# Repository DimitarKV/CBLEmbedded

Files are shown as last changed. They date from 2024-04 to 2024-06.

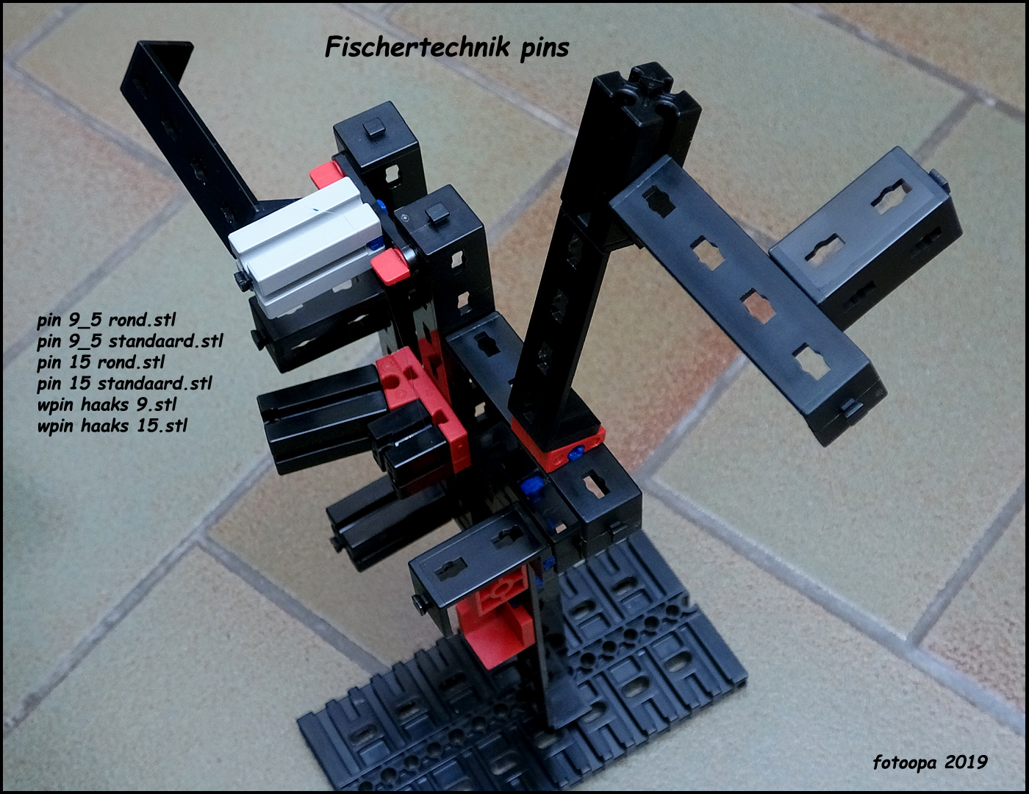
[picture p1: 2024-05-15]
Printing/Resources/Fischertechnik matching pins. - 4074749/images/DSC05036_pins.jpg

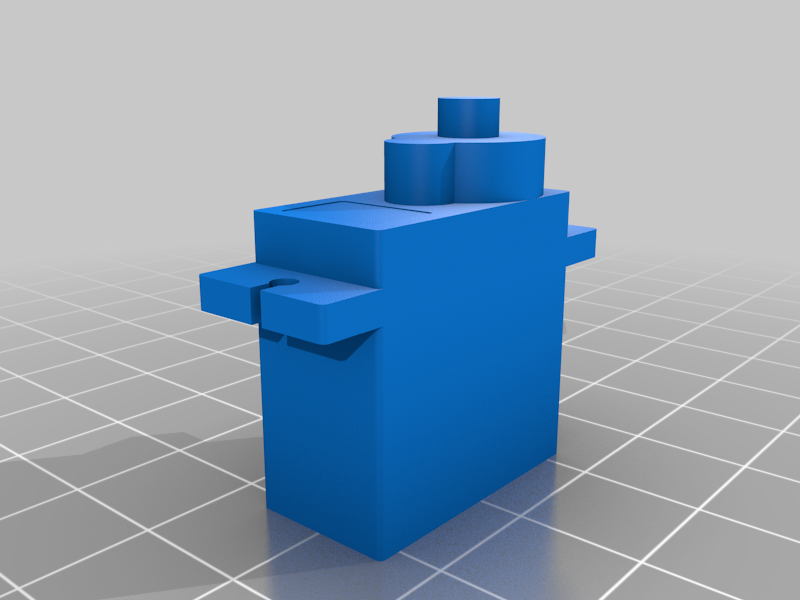
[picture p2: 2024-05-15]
Printing/Resources/Sg90 servo - 4315907/images/servoSg90.png

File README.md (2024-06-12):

# CBLEmbedded

## Description

A robot that simulates an unloading baggage-handling system in airports. In particular, it is intended to load a vehicle with luggage from an aircraft. Our baggage cart has three compartments, which will be filled by keeping their weights as equal as possible. The robot works on the principle that a new luggage is put in the most light-weighted compartment. There are two types of baggage – 10kg and 20kg. Luggage that was not intended for this flight will be placed in a separate container and moved to the lost and found. The capacity of each compartment is 40kg. When the current baggage cannot be stored in any of the compartments without exceeding the weight limit, the vehicle is ready to go. 

## How to use the project

- In the *Orchestrator* folder there are:
  - the Modbus Connector which creates another layer of abstraction over the Serial protocol used by both ends - ESP-32 and RaspberryPI;
  - the Driver which implements the whole logic of the robot using commands in the service layer;
  - the Portal which collects and preserves the measurements in csv files for later usage in our data model.
  - the Robot SeviceLayer which creates application specific implementation over Modbus;
  - the Simulation transfer server
- In the *Peripherals* folder there is implementation of functionality of the hardware devices, used in the robot:
  -  the Color sensor determines the behavior of the color sensor. Receives data and converts it in the needed form for the project;
  -  the Modbus connector handles Modbus communication over the serial connection. It includes methods for reading, decoding, processing, and responding to Modbus commands;
  -  the Depth sensor determines the behavior of the depth sensor. Receives data and converts it in the needed form for the project;
  -  the Motor driver controls a motor using four input pins. It provides methods to initialize the motor, move it by steps or length, check its status, and handle continuous movement;
  -  the Display determines the behavior of the display. Writes different type of messages depending on the state of the robot.
  -  the Servo controller manages multiple servos using the PCA9685 PWM driver. It provides methods to initialize the controller, add and configure servos, set angles immediately, and control servo progression;
  -  the Error prone device defines the basic functionality of the devices. Makes sure that the peripheral devices work properly;
  -  the Main manages various devices connected to the ESP-32.
- In the *Printing* folder there are 3D files of different holders for the hardware devices
- In the *Simulation* folder there is an exe file which contains the built simulation of the robot and all work files for the simulation created in Unity.

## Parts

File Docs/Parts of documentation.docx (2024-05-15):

// Commands:

// WDN{text} - Write Display No-scrolling, text is the string that is going to be displayed without scrolling.

// WDS{text} - Write Display Scrolling, text is the string that is going to be displayed scrolling on the screen.

// SSP{v1,v2,v3...} - Set Servo Values, set the corresponding values v1, v2, v3... to the corresponding servos.

// Handle collected serial commands from the buffer.

// We define a command name from the first three

// letters in the command, any consequent letters represent parameters.

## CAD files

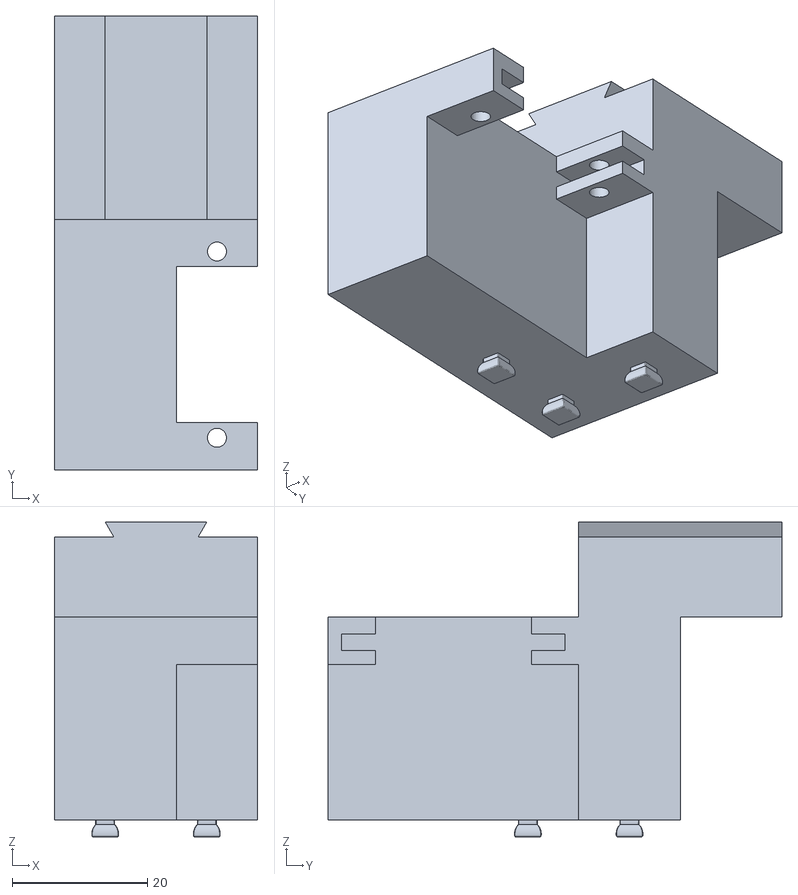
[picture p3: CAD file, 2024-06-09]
Printing/Ready/ServoPusherV7/Main frame.stl
30.0 x 67.0 x 46.5

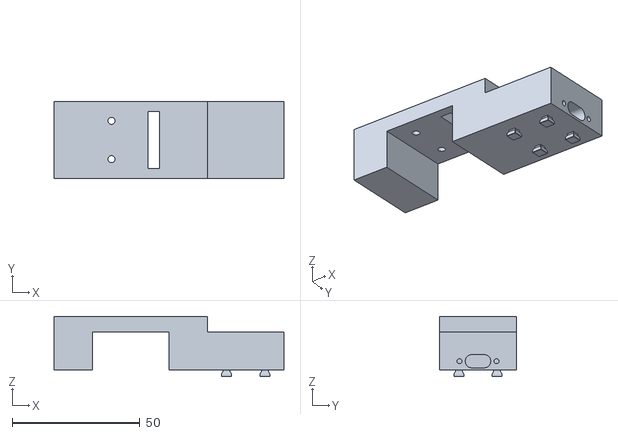
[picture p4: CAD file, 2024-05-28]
Printing/Ready/ColorDepthSensorMount/Frame.stl
90.0 x 30.0 x 23.5

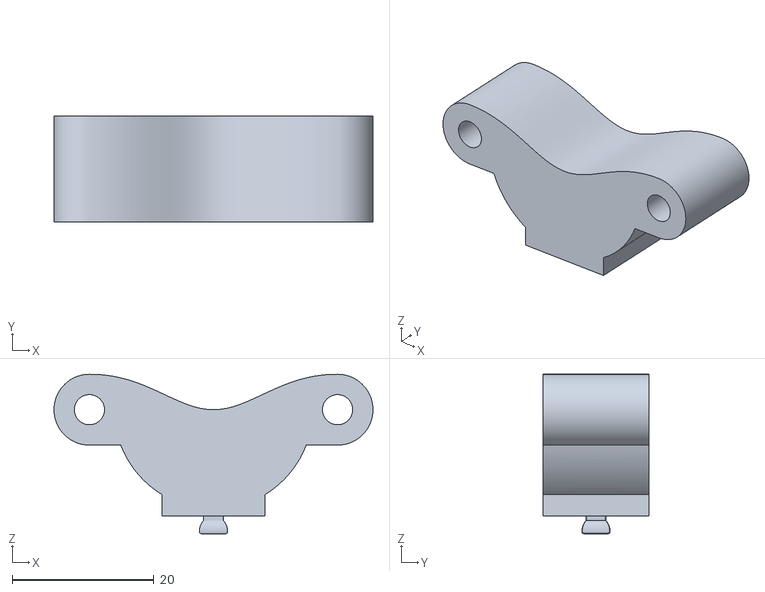
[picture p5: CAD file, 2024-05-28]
Printing/Ready/Motor/Mount.stl
45.0 x 15.0 x 22.5

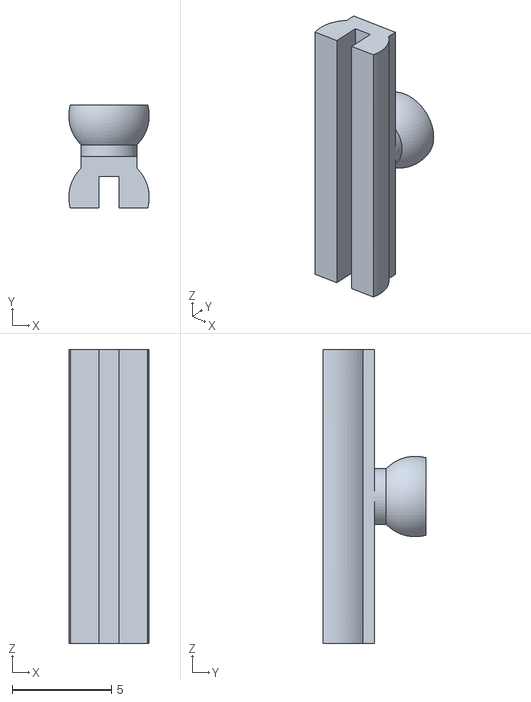
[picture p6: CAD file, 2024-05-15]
Printing/Resources/Fischertechnik matching pins. - 4074749/files/pin_15_rond.stl
4.05 x 5.20 x 14.8

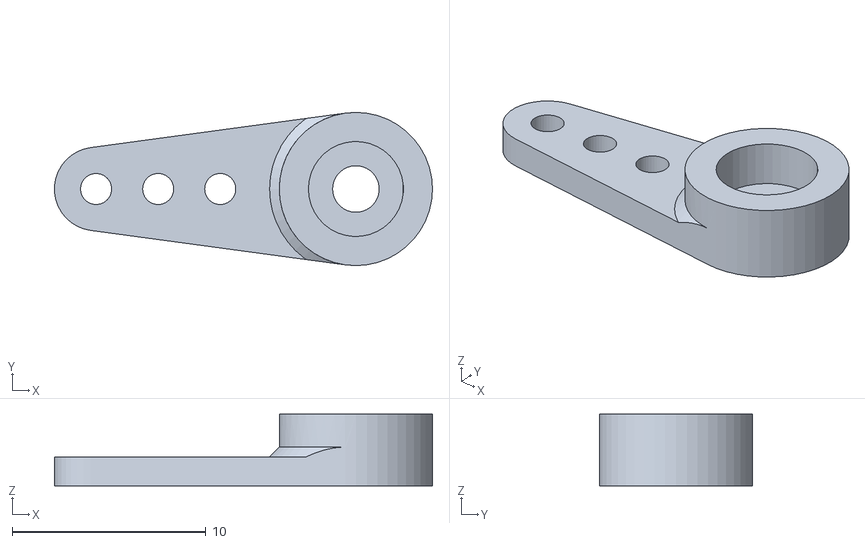
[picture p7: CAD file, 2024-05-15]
Printing/Resources/servo_arm.STL
19.5 x 7.90 x 3.70

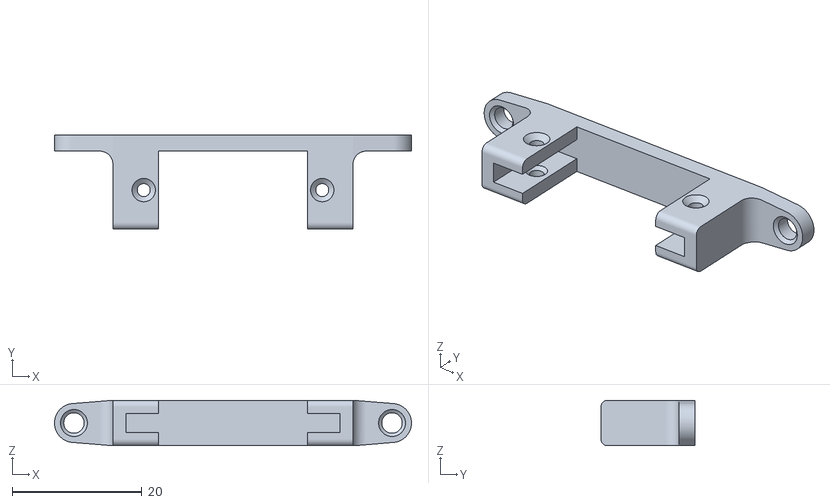
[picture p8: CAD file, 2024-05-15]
Printing/Resources/ServoMounts_SMA001_002_TERRN/PN_SMA002-4-24_TERRN.stl
55.0 x 14.5 x 7.00

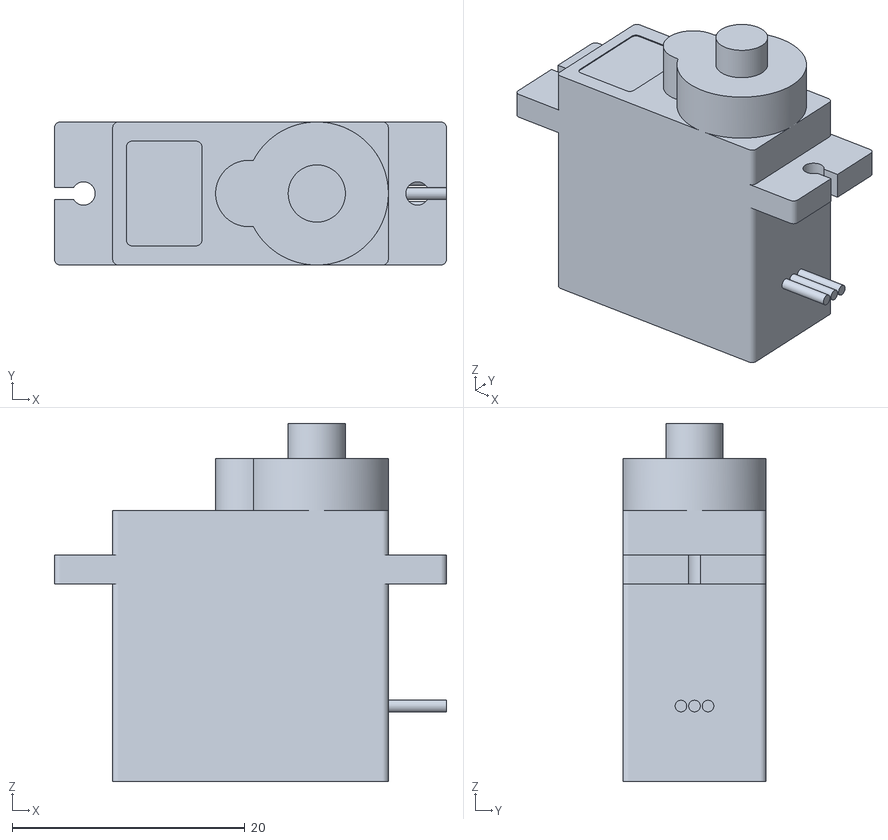
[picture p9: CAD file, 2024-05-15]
Printing/Resources/Sg90 servo - 4315907/files/servoSg90.stl
33.7 x 12.3 x 30.8

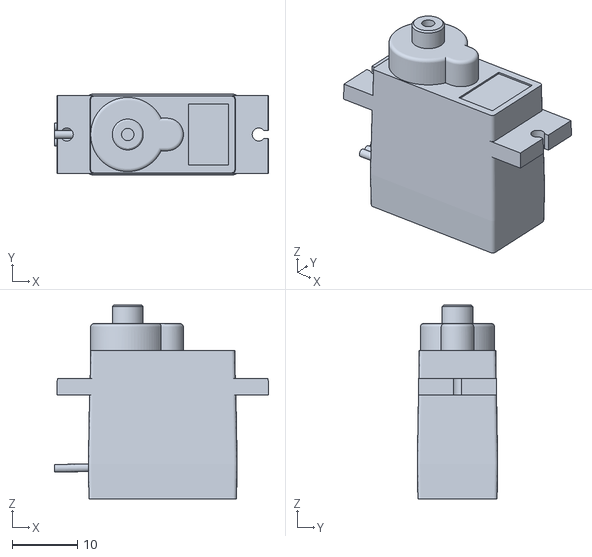
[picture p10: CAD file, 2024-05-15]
Printing/Resources/Tower Pro Micro Servo 9g SG90 - 787942/files/2051_servo_tower-pro-sg90.pk2.stl
32.9 x 12.4 x 29.8

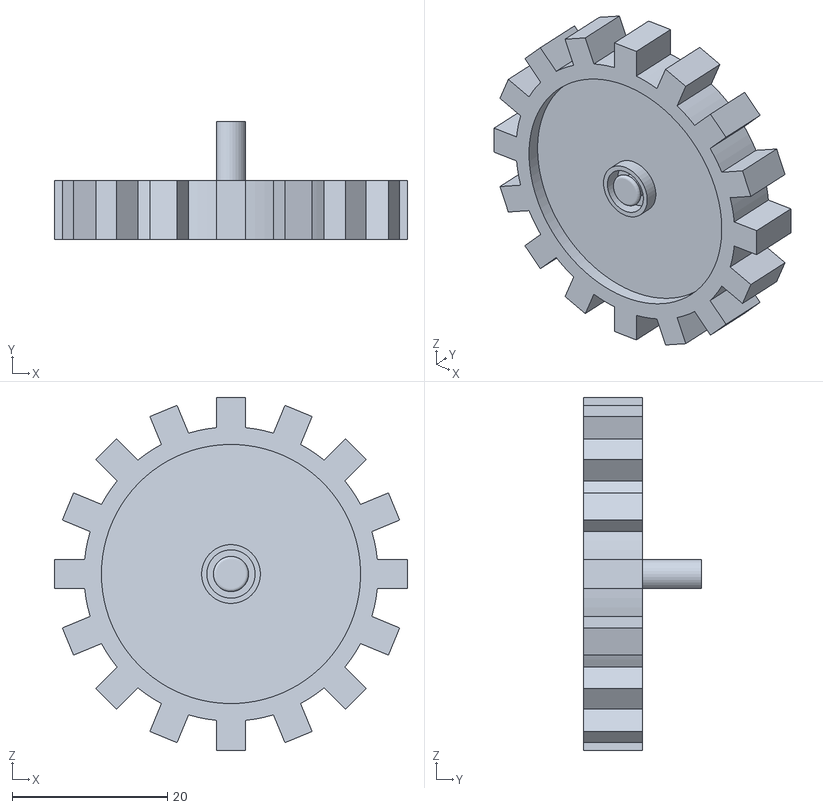
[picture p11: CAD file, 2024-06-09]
Simulation/LuggageSimulator/Assets/3DModels/gear wheel/gear wheel.stl
45.4 x 15.1 x 45.4

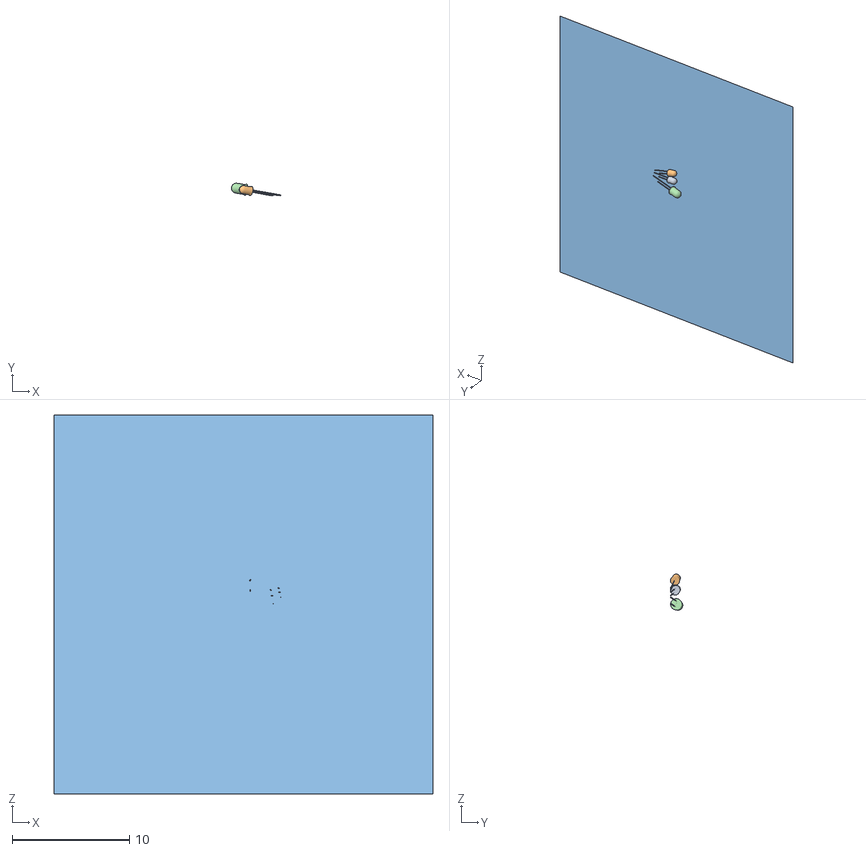
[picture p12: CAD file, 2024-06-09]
Simulation/LuggageSimulator/Assets/3DModels/Leds File/led.obj
32.3 x 1.08 x 32.3
Plane

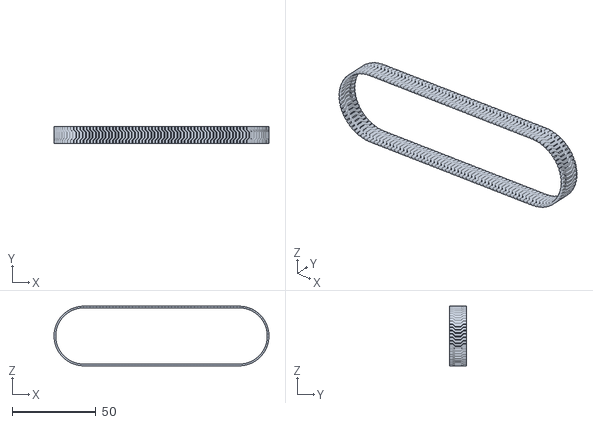
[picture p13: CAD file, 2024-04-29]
Simulation/LuggageSimulator/Assets/Materials/ImageToStl.com_alembic_test.obj
128.3 x 10.4 x 35.6

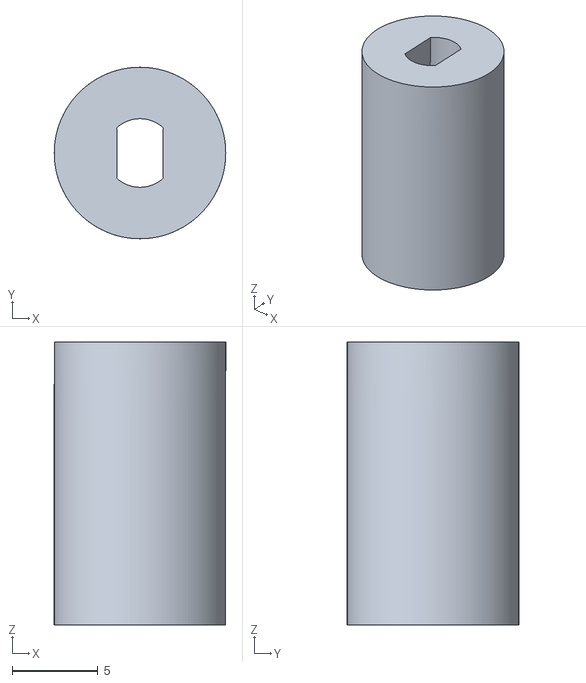
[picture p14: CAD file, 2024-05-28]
Printing/Ready/Motor/Adapter.stl
10.0 x 10.00 x 16.5

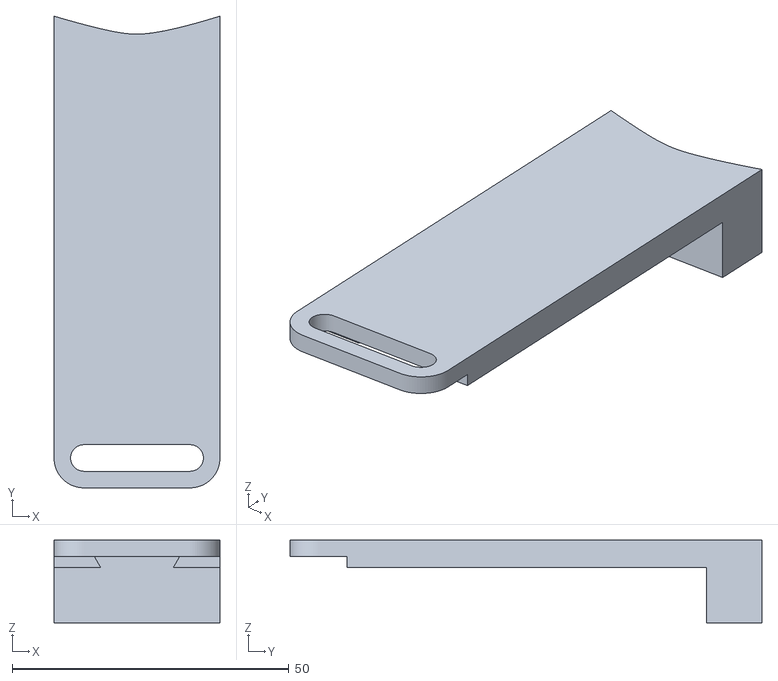
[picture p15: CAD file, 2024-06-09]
Printing/Ready/ServoPusherV7/Piston.stl
30.0 x 85.2 x 15.0

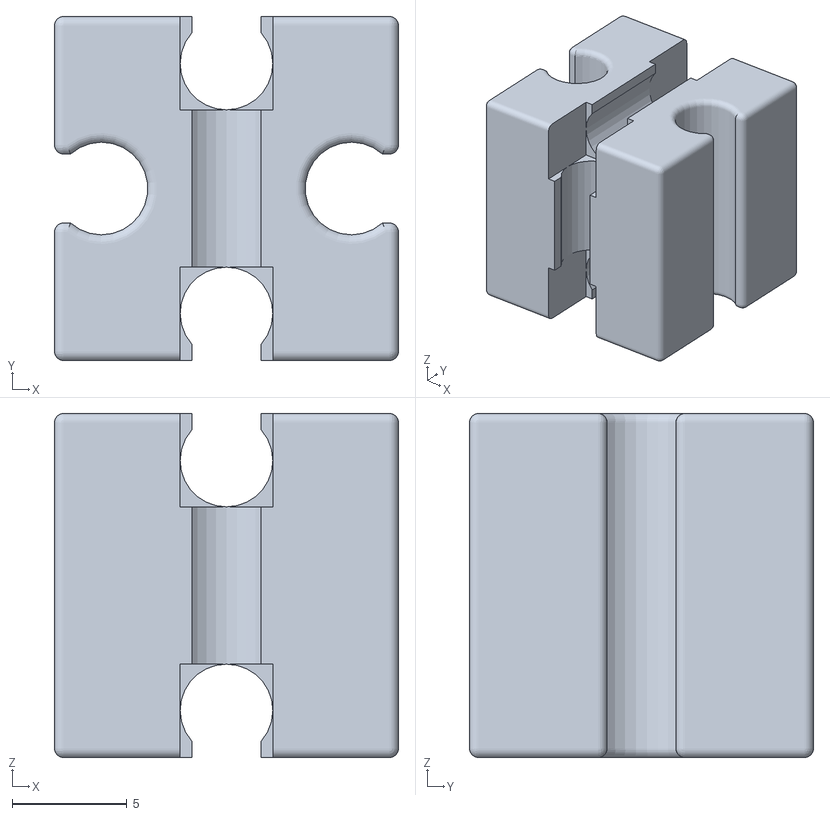
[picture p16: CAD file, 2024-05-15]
Printing/Resources/BS15_with_six_grooves_v1.stl
15.0 x 15.0 x 15.0

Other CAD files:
Printing/Resources/Fischertechnik matching pins. - 4074749/files/wpin_haaks_15.stl
Printing/Resources/ServoMounts_SMA001_002_TERRN/PN_SMA001-4-24_TERRN.stl
Printing/Ready/ServoPusherV7/Servo arm overlocker.stl
Printing/Resources/Fischertechnik matching pins. - 4074749/files/wpin_haaks_9.stl
Printing/Ready/DistributorV1/Main frame.stl
Printing/Ready/DistributorV1/Piston.stl
Printing/Ready/DistributorV1/Servo arm overlocker.stl
Printing/Ready/DistributorV1/Servo arm underpin.stl
Printing/Ready/ServoPusherV7/Servo arm underpin.stl
Printing/Resources/Fischertechnik matching pins. - 4074749/files/pin_15_standaard.stl
Printing/Resources/Fischertechnik matching pins. - 4074749/files/pin_9_5_rond.stl
Printing/Resources/Fischertechnik matching pins. - 4074749/files/pin_9_5_standaard.stl
Simulation/LuggageSimulator/Assets/3DModels/Leds File/led.blend

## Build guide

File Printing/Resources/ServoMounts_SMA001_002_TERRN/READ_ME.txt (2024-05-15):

Thank you for downloading this simple yet useful pack of two servo motor mounts by TERRN.DYNAMICS

These have been tested on the MG90S and SG90 servo motors, both fitting as intended. I am not sure
what other specific models of servo motors these mounts are compatible with but if you have any
suggestions to further mounts or other questions, please get in touch.

Please, use the blueprints provided to get accurate hole placements.

And lastly, I hope these two models will be found useful to you, and I wish you a lovely rest of your day.

All 3D models, instructions, and other assets created by TERRN.DYNAMICS remain under our copyright. 
This means you cannot distribute the original or modified assets without our permission. 
Thank you for respecting our rights.

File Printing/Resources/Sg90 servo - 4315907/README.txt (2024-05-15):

Sg90 servo by Theghost1790 on Thingiverse: https://www.thingiverse.com/thing:4315907

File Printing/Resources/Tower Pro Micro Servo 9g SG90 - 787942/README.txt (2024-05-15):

Tower Pro Micro Servo 9g SG90 by bathrobotics on Thingiverse: https://www.thingiverse.com/thing:787942

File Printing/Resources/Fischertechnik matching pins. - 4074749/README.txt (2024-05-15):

Fischertechnik matching pins. by fotoopa on Thingiverse: https://www.thingiverse.com/thing:4074749

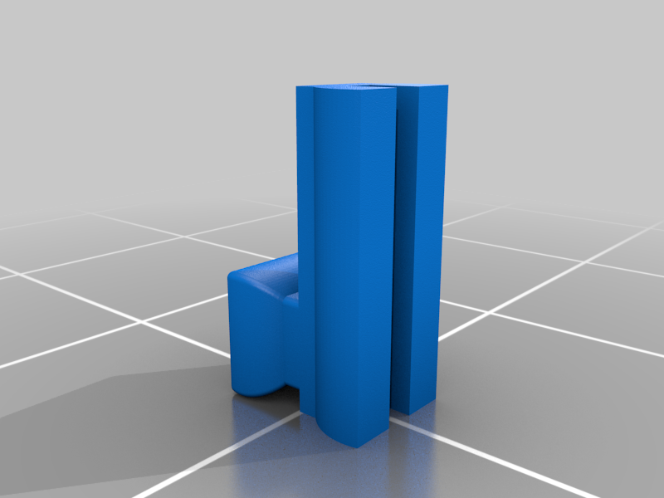
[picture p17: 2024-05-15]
Printing/Resources/Fischertechnik matching pins. - 4074749/images/pin_9_5_standaard.png

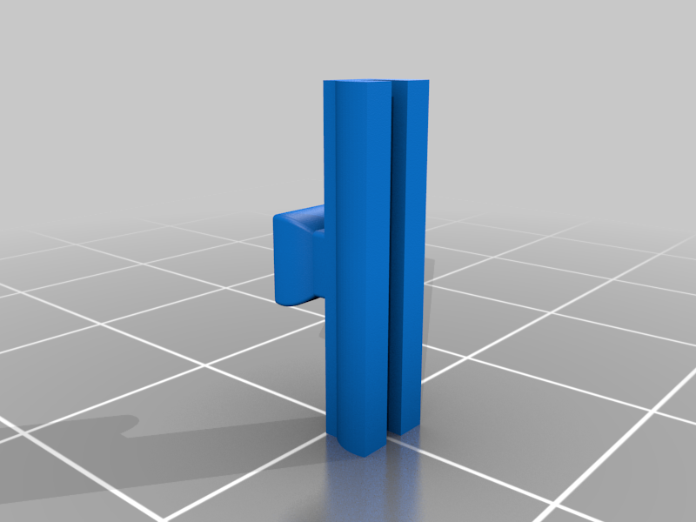
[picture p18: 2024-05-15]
Printing/Resources/Fischertechnik matching pins. - 4074749/images/pin_15_standaard.png

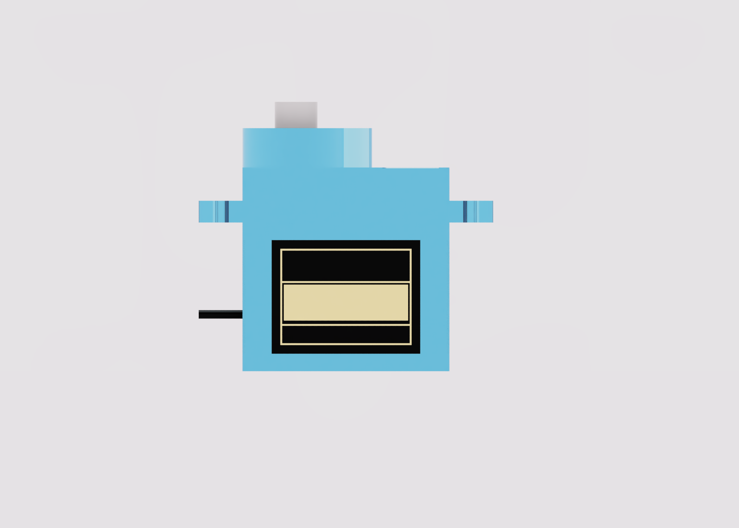
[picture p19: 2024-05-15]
Printing/Resources/Sg90 servo - 4315907/images/Sg90_2020-Apr-26_04-39-17PM-000_CustomizedView37391322986_png.png

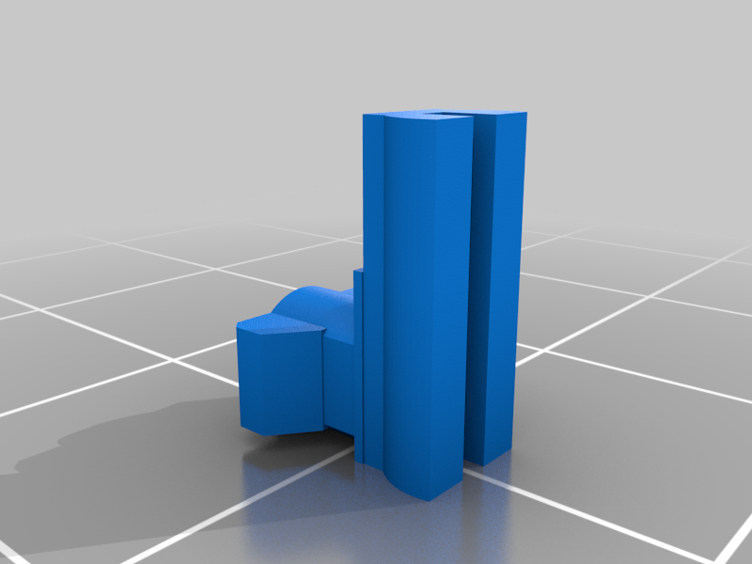
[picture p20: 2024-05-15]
Printing/Resources/Fischertechnik matching pins. - 4074749/images/wpin_haaks_9.png

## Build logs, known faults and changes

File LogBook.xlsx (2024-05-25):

Name (student no.) | Task (Due Date) | Finished Date | Hours spent (h)
Dimitar ()
Denitsa ()
Martina ()
Trayana ()
Hristo (1940651)
Dani (1969021)
Together

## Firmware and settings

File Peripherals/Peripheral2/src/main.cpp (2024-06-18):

#define LOG_LOCAL_LEVEL ESP_LOG_NONE
#include <Arduino.h>

#include <Wire.h>

#include <../lib/modbus_connector/modbus_connector.h>
#include <../lib/color_sensor/color_sensor.h>
#include <../lib/display_interface/display_interface.h>
#include <../lib/servo_shield/servo_controller.h>
#include <../lib/motor_driver/motor_driver.h>
#include <../lib/depth_sensor/depth_sensor.h>
#include <../lib/led_driver/led_driver.h>

#include <Adafruit_ST7789.h>
#include <Adafruit_GFX.h>

/**
 * Manages various devices connected to the ESP-32, including a Modbus connector,
 * a display, a color sensor, a servo controller, a motor driver, and a depth sensor. It initializes and 
 * coordinates these components to handle Modbus communication, perform sensor readings, control servos, 
 * and operate a motor.
 */

#define STEPPER_IN1 5
#define STEPPER_IN2 6
#define STEPPER_IN3 7
#define STEPPER_IN4 3

ModbusConnector connector;
Display display = Display(10, 2, 4);
ColorSensor colorSensor = ColorSensor(21, 1);
ServoController servoController = ServoController();
MotorDriver motorDriver(STEPPER_IN1, STEPPER_IN3, STEPPER_IN2, STEPPER_IN4);
DepthSensor depthSensor;
LedDriver ledDriver;
bool devicesLocked = false;

TaskHandle_t HandleConnectorTaskHandle;
void HandleConnector(void *parameter)
{
  while (true)
  {
    connector.tick();
    motorDriver.tick();
  }
}

void writeToDisplay(ModbusPacket inputPacket)
{
  display.interpretMessage((char *)inputPacket.data);
}

void readColorSensor(ModbusPacket packet)
{
  ColorSensorData data = colorSensor.getData();
  connector.sendData((byte *)(&data), 12);
}

void readDepthSensor(ModbusPacket packet)
{
  byte reading = depthSensor.getLastReading();
  connector.sendData(&reading, 1);
}

void setServoAngles(ModbusPacket packet)
{
  if (packet.dataLength % 2 == 0)
  {
    servoController.setImmediateAngles(packet.data, packet.dataLength);
  }
}

void setServoProgressions(ModbusPacket packet)
{
  if (packet.dataLength % 2 == 0)
  {
    servoController.setServoProgressions(packet.data, packet.dataLength);
  }
}

void moveBelt(ModbusPacket packet)
{
  short *distance = (short *)(&packet.data);
  motorDriver.moveLength(*distance);
  
}

void moveBeltSteps(ModbusPacket packet) {
  short *steps = (short *)(&packet.data);
  motorDriver.moveSteps(*steps);

}

void moveBeltContinuous(ModbusPacket packet)
{
  if(packet.data[0] == 0)
    motorDriver.moveContinuous(false);
  else if(packet.data[0] == 1)
    motorDriver.moveContinuous();
}

void isMotorMoving(ModbusPacket packet) {
  bool isMoving = motorDriver.isMoving();
  connector.sendData((byte*)&isMoving, 1);
}

void checkStatus(ModbusPacket packet) {
  connector.sendData((byte*)&devicesLocked, 1);
}

void setLedLevel(ModbusPacket packet) {
  byte states = packet.data[0];
  Serial1.println(states);
  for (int i = 0; i < 8; i++)
  {
    ledDriver.setLedOn(i, (states >> i) & 1);
  }
}

void lockDevices() {
  colorSensor.lock();
  depthSensor.lock();
  motorDriver.lock();
  devicesLocked = true;
}

void unlockDevices() {
  colorSensor.lock(false);
  depthSensor.lock(false);
  motorDriver.lock(false);
  devicesLocked = false;
}

void setup()
{
  Wire1.setPins(21, 1);
  Serial.begin(1000000);
  Serial1.begin(115200);
  Serial1.println("Here");

  display.init(135, 240, 3);
  colorSensor.init();
  motorDriver.init();
  servoController.init();
  depthSensor.init();
  ledDriver.init();

  for (int i = 0; i < 8; i++)
  {
    ledDriver.setLedOn(i, false);
  }
  

  servoController.addServo(0, 100, 50);
  servoController.addServo(1, 170, 10);
  servoController.addServo(2, 170, 10);
  servoController.addServo(3, 170, 10);

  connector.addProcessor(0, *writeToDisplay);
  connector.addProcessor(1, *readColorSensor);
  connector.addProcessor(2, *moveBelt);
  connector.addProcessor(3, *setServoAngles);
  connector.addProcessor(4, *readDepthSensor);
  connector.addProcessor(5, *checkStatus);
  connector.addProcessor(6, *setServoProgressions);
  connector.addProcessor(7, *moveBeltContinuous);
  connector.addProcessor(8, *moveBeltSteps);
  connector.addProcessor(9, *isMotorMoving);
  connector.addProcessor(10, *setLedLevel);

  xTaskCreatePinnedToCore(
      HandleConnector,
      "Connector handler",
      10000,
      NULL,
      0,
      &HandleConnectorTaskHandle,
      0);
}

void loop()
{
  connector.deviceStatus = 
  (!colorSensor.status_check() * 1) +
  (!depthSensor.status_check() * 0b10);

  if (connector.deviceStatus != 0) {
    lockDevices();
  } else {
    unlockDevices();
  }
  
  colorSensor.tick();
  depthSensor.tick();
}

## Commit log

2024-04-23 Added logbook form
    [LogBook.xlsx]
2024-04-26 Added first peripheral device implementation initialization
2024-04-29 Added initial Peripherals code to interface with the display and also added the initial simulation
    [ImageToStl.com_alembic_test.obj]
2024-05-02 Created a file to keep track of pieces of documentation which needs heavy further structuring
2024-05-04 Finished Modbus connector on Arduino side and managed to fix heap fragmentation as far as I can tell, server side not yet implemented for adapted Modbus communication protocol.
    [main.cpp]
2024-05-04 Fixed some LRC issues and made WebApi Peripheral communication more abstract
    [main.cpp]
2024-05-05 Started implementing device querying on Arduino side
2024-05-05 Did some logic on the web api for reading from the device, but nothing works until now
2024-05-05 Pulled connector implementation to a separate class library so it can be easily used in other applications
2024-05-05 Tested roundtrip response time with current set up and concluded that the baud rate is not the limiting factor
2024-05-13 Color sensor code 1
    [LogBook.xlsx]
2024-05-13 Handling errors for color sensor
    [main.cpp]
2024-05-14 Added Peripheral2 meant to be running on an ESP32
    [2051_servo_tower-pro-sg90.pk2.stl, BS15_with_six_grooves_v1.stl, Main frame.stl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]
2024-05-14 Moved ready for print files out from resources
    [Main frame.stl, Piston.stl, Servo arm overlocker.stl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]
2024-05-14 Fixed some display bugs
    [main.cpp]
2024-05-14 Add files via upload
    A simulation of the actual process each time the color sensor sends signal of a new correct disk.
2024-05-15 Conveyor belt try
2024-05-15 Created the Color Sensor library
2024-05-15 Added proximity sensor code
2024-05-15 Initial motor project
2024-05-17 Gear WHeel
    [gear wheel.stl]
2024-05-17 Added color detection method, javadoc comments and library fixes
    [main.cpp]
2024-05-17 Fixed latest issues, Added RGB to HSV converter
    [main.cpp]
2024-05-19 Motor library
2024-05-19 ServoShield library added.
2024-05-20 Update servo_shield.h
    Added some properties for variable motion speed
2024-05-20 Started working on easing servo motion
2024-05-20 Fixed display interface and moved color sensor code to main code
    [main.cpp]
2024-05-21 Fixed some issues and added linear servo motion
    [main.cpp]
2024-05-25 Finished servo base functionality
2024-05-25 Added orchestrator servo functionality
2024-05-26 Altered motor logic and got rid of the usual stepper library and wrote an asynchronous one for our application
2024-05-26 Basic functionality of color sensor done
2024-05-26 Reverted to a point before merge with main
    [main.cpp]
2024-05-27 Started modbus part of the color sensor, but found a bug in the modbus connector implementation, leaving this feature branch for now
    [main.cpp]
2024-05-27 Added motor logic for directions
2024-05-27 Step motor server logic done
2024-05-28 Created the web api client server and finished 3d printed parts
    [Adapter.stl, Frame.stl, Main frame.stl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]
2024-05-29 Added frontend color sensor data rendering
2024-05-29 Implemented depth sensor in Simulation transfer server (We need to rename the server again)
2024-05-29 Changed color sensor pins to unused ones
2024-05-30 Implemented the logic of the robot in the simulation
    [led.blend, led.obj]
2024-05-31 Optimization in the esp32 code to run the two cores
    [Main frame.stl, Piston.stl, Servo arm overlocker.stl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]
2024-06-04 Modifications to the depth sensor efficiency
2024-06-04 Changed servo controller code to be more robust and added some untested features like the servo progressions
2024-06-05 Logic partly
    [black.csv, empty.csv, white.csv]
2024-06-05 Add Plot for the data
    [white.csv]
2024-06-05 Collected some valuable color sensor data for possible linear regression fitting
    [black.csv, empty.csv, white.csv]
2024-06-05 Tried to make the conveyor belt rotate, did not succeed
2024-06-06 Screen printing in a canvas partially working
2024-06-07 Line guessing the measurements
    [black.csv, black120ms.csv, empty120ms.csv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]
2024-06-08 Hopefully finished the color sensor code
2024-06-09 Added some error handling and changed modbus messaging signature, needs more work to make it fully robust
    [black.csv]
2024-06-09 Added Color sensor interpreter to main project
2024-06-11 Added some logic
    [empty.csv]
2024-06-12 Started working on error handling, still not completelly working
    [main.cpp]
2024-06-12 Final version done
    [misc_black.csv, misc_white.csv]
2024-06-14 Tweaked color values and sound timing
    [bulk.csv, classified.csv]
2024-06-18 Small adjustments for performance increase
    [bulk.csv, classified.csv]
2024-06-18 Removed some troublesome parts is Driver csproj
